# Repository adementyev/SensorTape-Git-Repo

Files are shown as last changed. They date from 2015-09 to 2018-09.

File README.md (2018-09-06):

# SensorTape Project 

## Introduction 
SensorTape is a sensor network in a form factor of a tape. It allows users to intuitively create large sensor networks. See mode details in the paper from [UIST](http://artem.dementyev.us/wp-content/uploads/2013/10/Sensor_tape_UIST_2015_rev9_FINAL.pdf) conference and a video 
This repository contains all the hardware and software design files to make SensorTape. 

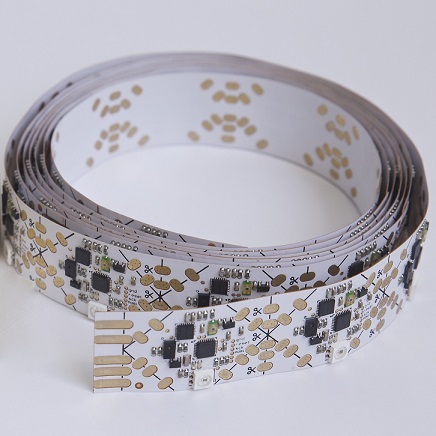
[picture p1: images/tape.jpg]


## Content
Master_hw/ - Hardware files for the master board in Altium format. Can be used to make the board

Slave_hw/ - Hardware files for the tape itself, refered here as the slave. This is the flexible circuit version of the tape 

Prog_adapter_hw/ -  Hardware files for the programming board, use it to program both the slave and the master. 

libraries/ - Collection of the Arduino libraries for the master and the slave. Those libraries are required 

Firmware/ - Firmware for both the master and the slave

SensorTape_Demo_V1/ - Processing sketch for a simple visualization demo. Demonstrates the basics of interfacing with a PC. 

## Getting Started
Connect the mini USB port on the master board to the computer. The master board has two usb ports and the micro USB port is only for 5V power. 
Connect the tape to the master using the FPC connector on the master. Make sure it secured. The tape has to be placed in the right orientation. There are 5 wires on the tape and the master, and they should match up. See the picture below. 

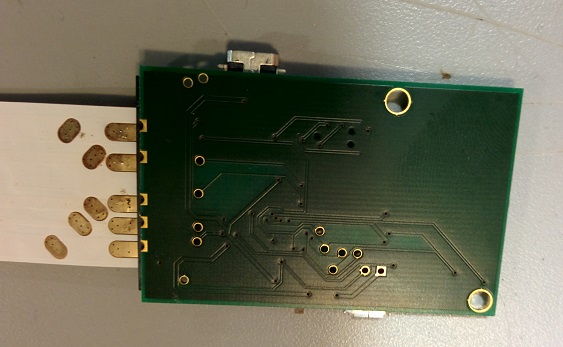
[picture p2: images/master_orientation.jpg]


Turn the switch on the master. The sensor nodes on the tape should light up. 
Once the initialization is done, the blue light will start blinking. 
The raw data can be seen on the serial terminal (at 115200 baud rate) 
The data visaulization can be done using the SensorTape_Demo_V1 software for Processing. In the code SensorTape_Demo_V1.pde. There is a line which defines number of nodes: 
int numberOfNodes = 16; 
This should be changed to the number you have, to make debugging easier. 
Also, if the number is incorrect, 3D visualizations will be messed up. 

The IMU sensors need some time to calibrate (about 30 seconds) after powering on. If they are moved during the time the orientation vectors will be messed up. 

## Firmware 
Add the arduino libraries from the libraries/ folder here to the worspace libraries folder. 
You will need the following libraries Adafruit_NeoPixel, I2C_dev, MPU6050, and VL6180X_I2C_Soft

you will need a programmer and an adapter board (Prog_adapter_hw/) to load the software. I used AVRISP mKII.
you will need to load the bootloader first into the boards. This will set the fuses and the clock frequency. Use the Arduino Micro (3.3V, 8 MHz) for the slaves and Arduino leonardo for the master. Set those before loading the bootloader

## PC software
I used Processing 3. You will need one external library (toxiclibs-complete-0020), it is in the libraries folder. 

## Slave
The slaves are basically the tape. The tape is made of strips with 6 slave nodes. You will need a flexible PCB factory to manufacture. The factories in china are innexpensive and have good quality. They can be found on alibaba.com. Also it is better to get it assembled profesionally, since hand assembly is difficult. I had a lot of problems with the packaging of proximity sensor melting in my reflow owen. 

The programming connector can be hard to attach on the first try, since it is just pressfitted. 

When starting the tape wait about a minute for the IMUs to calibrate, otherwise the orientaion data will drift

## Master
Master moves the data from the slaves to the PC. I am using an ATMega32u4 microcontroller, which works as a USB modem. 

## Known Issues
1. Proximity sometimes dont work if tape is restarted. I suspect that they don't have time to fully discharge. When turning the tape on and off or restarting, wait some time to turn it back on. 
2. The number of nodes is set pn the PC side in the current version. So the nodes dont need to be reset each time PC software is restarted. 

## Manufacturing and Design 
There are three parts needed for manufacturing: 
1) Manufacturing the flexible circuits 
2) Sourcing the parts 
3) Assembly (parts+flex circuit = done!)

We encourage manufacturing the SensorTape from the source files. There are numerous board houses that can do flexible electronics. The prices in the US are quite expensive (few thousand $$$), and the same boards can be made in China for a fraction of the price(few hundred $$$). On the other hand, it is easier to communicate with the US-based manufacturers. The Chinese board houses can be found and contacted directly on places such as Alibaba.com. 

The parts can be bought easily from US-based large electronics sellers such as Digikey.com. If you want the parts cheaper, go through Alibaba.com. It is more difficult, but can be cheaper especially for the ICs. 

The assembly should be done by a factory also, using professional equipment. Doing it by hand is possible, but requires a good reflow oven. The oven needs to have even temperature distribution, since proximity sensor packaging can easily melt. There are numerous assembly houses in the US, such as Advanced Circuits. They have reasonable prices (around a thousand). There are also assembly houses in China, that area cheaper, but once again are more difficult to contact.  

## Aknowledgements
MIT Media Lab, Nan-Wei Gong, Cindy Kao, Nan Zhao, Felix Heibeck, National Sceince Foundation. 
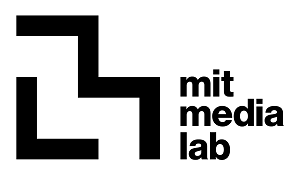
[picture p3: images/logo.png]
MediaLab Logo


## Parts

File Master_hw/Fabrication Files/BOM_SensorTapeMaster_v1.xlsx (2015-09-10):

Description | Quantity | Footprint | Comment | Manufacturer | Mfg Part # | Digikey Part # | Designator
Resistors
RES SMD 4.7K OHM 5% 1/10W 0603 | 2 | 0603 | Generic, can be subsituted with another manufacturer | Yageo | RC0603JR-074K7L | 311-4.7KGRCT-ND | R4,R5
RES SMD 1K OHM 5% 1/10W 0603 | 3 | 0603 | Generic, can be subsituted with another manufacturer | Yageo | RC0603JR-071KL | 311-1.0KGRCT-ND | R1,R3,R9
RES SMD 10K OHM 1% 1/10W 0603 | 2 | 0603 | Generic, can be subsituted with another manufacturer | Stackpole | RMCF0603FT10K0 | RMCF0603FT10K0CT-ND | R6,R12
RES SMD 22 OHM 5% 1/10W 0603 | 2 | 0603 | Generic, can be subsituted with another manufacturer | Yageo | RC0603JR-0722RL | 311-22GRCT-ND | R7,R8
RES ARRAY 330 OHM 4 RES 1206 | 1 | 1206 |  | Panasonic | EXB-38V331JV | Y9331CT-ND | R13
RES SMD 0.0OHM JUMPER 1/10W 0603 | 2 | 603 | Generic, can be subsituted with another manufacturer | Rohm | MCR03EZPJ000 | RHM0.0GCT-ND | R2,R10
Capacitors
CAP CER 0.1UF 16V 10% X7R 0603 | 4 | 0603 | Generic, can be subsituted with another manufacturer | Murata | GRM188R71C104KA01D | 490-1532-1-ND | C3, C4, C5, C8
CAP CER 10UF 6.3V 20% X5R 0603 | 3 | 0603 | Generic, can be subsituted with another manufacturer | Taiyo Yuden | JMK107ABJ106MAHT | 587-3383-1-ND | C1, C2, C9
CAP CER 1UF 10V 10% X7R 0603 | 1 | 0603 | Generic, can be subsituted with another manufacturer | Samsung | CL10B105KP8NNNC | 1276-1946-1-ND | C7
CAP CER 22PF 50V 5% C0G 0603 | 2 | 0603 | Generic, can be subsituted with another manufacturer | TDK | C1608C0G1H220J080AA | 445-1273-1-ND | C10,C11
LEDs
LED 468NM BLUE CLEAR 0603 SMD | 1 | 0603 |  | Lite-On Inc | LTST-C191TBKT | 160-1647-1-ND | L1
LED SUPER RED CLR THIN 0603 SMD | 2 | 0603 |  | Lite-On Inc | LTST-C191KRKT | 160-1447-1-ND | L2, L5
LED RED ORAN CLEAR THIN 0603 SMD | 1 | 0603 |  | Lite-On Inc | LTST-C191KFKT | 160-1445-1-ND | L3
LED WHITE 0603 SMD | 1 | 0603 |  | Lite-On Inc | LTW-C193TS5 | 160-1721-1-ND | L4
LED GREEN CLEAR THIN 0603 SMD | 1 | 0603 |  | Lite-On Inc | LTST-C191KGKT | 160-1446-1-ND | L6
LED RGB WS2812B 5050 W/DVR 10PK | 1 | 5050 |  | Adafruit | 1655 | 1528-1104-ND | L7
Resonators
Crystal 16.0000MHz 30ppm 18pF 60 Ohm | 1 | 4-SMD, No Lead (DFN, LCC) |  | CTS | 405C35D16M00000 | CTX820CT-ND | O2
ICs
IC MCU 8BIT 32KB FLASH 44QFN | 1 | 44-TQFP (10x10) |  | Atmel | ATMEGA32U4-AU | ATMEGA32U4-AU-ND | U5
IC LOAD SW CTRL 1CH SOT-25 | 1 | SOT-25 |  | Diodes inc | AP2280-1WG-7 | AP2280-1WGDICT-ND | U7
IC SWITCH HIGH SIDE SC70-6 | 1 | 6-TSSOP |  | Vishay | SIP32431DR3-T1GE3 | SIP32431DR3-T1GE3CT-ND | U4
MODULE BLUETOOTH V2.1+EDR | 1 | 35-SMD Module |  | Microchip | RN42-I/RM | 740-1038-ND | U1
IC REG LDO 3.3V 0.15A SOT23-5 | 1 | SOT-23-5 |  | Micrel | MIC5205-3.3YM5 TR | 576-1259-1-ND | U6
DNP | 1 | SOT-23-5 | DNP | Micrel | MIC5205-3.3YM5 TR | 576-1259-1-ND | U6
MAGNETOMETER XYZ DIGITAL 10DFN | 1 | 10-DFN (2x2) | Optional | Freescale | MAG3110FCR1 | MAG3110FCR1CT-ND | U3
Connectors
CONN FPC TOP 25POS 1.00MM | 1 |  |  | TE Connectivity | 2-84953-5 | A101410CT-ND | P6
Connector Receptacle USB - micro B | 1 |  |  | Hirose | ZX62-B-5PA(11) | H11634CT-ND | P3
Connector Receptacle USB - min | 1 |  |  | Hirose | UX60SC-MB-5ST(80) | H11671CT-ND | P4
TEST POINT PC MINI .040"D RED | 12 |  | DNP | Keystone electronics | 5000 | 36-5000-ND | TP1, TP2, TP3, TP4, TP5, TP6, TP7, TP8, TP9, TP10, TP11, TP12
Switches
SWITCH TACTILE SPST-NO 0.02A 15V | 1 |  |  | Panasonic | EVQ-Q2B02W | P12931SCT-ND | S1
SWITCH SLIDE SPDT 0.4VA 28V | 1 |  |  | NKK Switches | SS312SAH4-R | 360-2924-1-ND | S2

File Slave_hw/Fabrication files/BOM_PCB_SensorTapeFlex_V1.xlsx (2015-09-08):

Parts for one strip (6 identical circuits)
Description | Quantity | Footprint | Comment | Manufacturer | Mfg Part # | Digikey Part # | Designator
Capacitors
CAP CER 0.1UF 16V 10% X7R 0603 | 24 | 0603 | Generic, can be subsituted with another manufacturer | Murata | GRM188R71C104KA01D | 490-1532-1-ND | C1, C1_1, C1_1_1, C1_1_1_1, C1_1_1_2, C1_1_2, C2, C2_1, C2_1_1, C2_1_1_1, C2_1_1_2, C2_1_2, C5, C5_1, C5_1_1, C5_1_1_1, C5_1_1_2, C5_1_2, C6, C6_1, C6_1_1, C6_1_1_1, C6_1_1_2, C6_1_2
CAP CER 10000PF (10nF) 50V 10% X7R 0603 | 6 | 0603 | Generic, can be subsituted with another manufacturer | Murata | GRM188R71H103KA01D | 490-1512-1-ND | C3, C3_1, C3_1_1, C3_1_1_1, C3_1_1_2, C3_1_2
CAP CER 2200PF 50V 5% NP0 0603 | 6 | 0603 | Generic, can be subsituted with another manufacturer | Murata | GRM1885C1H222JA01D | 490-1459-1-ND | C4, C4_1, C4_1_1, C4_1_1_1, C4_1_1_2, C4_1_2
CAP CER 10UF 6.3V 20% X5R 0603 | 18 | 0603 | Generic, can be subsituted with another manufacturer | Taiyo Yuden | JMK107ABJ106MAHT | 587-3383-1-ND | C7, C7_1, C7_1_1, C7_1_1_1, C7_1_1_2, C7_1_2, C8, C8_1, C8_1_1, C8_1_1_1, C8_1_1_2, C8_1_2, C9, C9_1, C9_1_1, C9_1_1_1, C9_1_1_2, C9_1_2
Resistors
RES SMD 4.7K OHM 5% 1/10W 0603 | 6 | 0603 | Generic, can be subsituted with another manufacturer | Yageo | RC0603JR-074K7L | 311-4.7KGRCT-ND | R3, R3_1, R3_1_1, R3_1_1_1, R3_1_1_2, R3_1_2
RES SMD 1K OHM 1% 1/10W 0603 | 6 | 0603 | Generic, can be subsituted with another manufacturer | Yageo | RC0603FR-071KL | 311-1.00KHRCT-ND | R7, R7_1, R7_1_1, R7_1_1_1, R7_1_1_2, R7_1_2
RES SMD 47K OHM 1% 1/10W 0603 | 12 | 0603 | Generic, can be subsituted with another manufacturer | Yageo | RC0603FR-0747KL | 311-47.0KHRCT-ND | R8, R8_1, R8_1_1, R8_1_1_1, R8_1_1_2, R8_1_2, R9, R9_1, R9_1_1, R9_1_1_1, R9_1_1_2, R9_1_2
RES SMD 330 OHM 1% 1/10W 0603 | 12 | 0603 | Generic, can be subsituted with another manufacturer | Yageo | RC0603FR-07330RL | 311-330HRCT-ND | R10, R10_1, R10_1_1, R10_1_1_1, R10_1_1_2, R10_1_2, R11, R11_1, R11_1_1, R11_1_1_1, R11_1_1_2, R11_1_2
RES SMD 10K OHM 1% 1/10W 0603 | 24 | 0603 | Generic, can be subsituted with another manufacturer | Stackpole Electronics | RMCF0603FT10K0 | RMCF0603FT10K0CT-ND | R1, R1_1, R1_1_1, R1_1_1_1, R1_1_1_2, R1_1_2, R2, R2_1, R2_1_1, R2_1_1_1, R2_1_1_2, R2_1_2, R4, R4_1, R4_1_1, R4_1_1_1, R4_1_1_2, R4_1_2, R6, R6_1, R6_1_1, R6_1_1_1, R6_1_1_2, R6_1_2
Resonators
CER RESONATOR 8.00MHZ SMD | 6 | 3-SMD, Non-Standard |  | Murata | CSTCE8M00G55-R0 | 490-1195-1-ND | O1, O1_1, O1_1_1, O1_1_1_1, O1_1_1_2, O1_1_2
LEDs
WS2812S 6 pin RGB LED | 6 | 5050 | Has to be the 6 pin version (S version) | Worldsemi | WS2812S |  | L1, L1_1, L1_1_1, L1_1_1_1, L1_1_1_2, L1_1_2
LED 468NM BLUE CLEAR 0603 SMD | 6 | 0603 | Generic, can be subsituted with another manufacturer | Lite-On Inc | LTST-C191TBKT | 160-1647-1-ND | L2, L2_1, L2_1_1, L2_1_1_1, L2_1_1_2, L2_1_2
LED SUPER RED CLR THIN 0603 SMD | 6 | 603 | Generic, can be subsituted with another manufacturer | Lite-On Inc | LTST-C191KRKT | 160-1447-1-ND | L3, L3_1, L3_1_1, L3_1_1_1, L3_1_1_2, L3_1_2
ICs
AMBIENT LIGHT SENSOR 1206 SMD | 6 | 1206 |  | Vishay | TEMT6000X01 |  | T1, T1_1, T1_1_1, T1_1_1_1, T1_1_1_2, T1_1_2
GYRO/ACCELEROMETER 6AXIS 24QFN | 6 | QFN24 |  | Invensense | MPU-6050 |  | U1, U1_1, U1_1_1, U1_1_1_1, U1_1_1_2, U1_1_2
ATmega328P-MUR | 6 | 32-VFQFN Exposed Pad |  | Atmel | ATMEGA328P-MU |  | U2, U2_1, U2_1_1, U2_1_1_1, U2_1_1_2, U2_1_2
MOD TIME-OF-FLIGHT 3IN1 12LGA | 6 | 12LGA |  | STMicroelectronics | VL6180XV0NR/1 |  | U3, U3_1, U3_1_1, U3_1_1_1, U3_1_1_2, U3_1_2
IC REG LDO 2.8V 0.15A SOT23-5 | 6 | SOT-23-5 |  | Micrel | MIC5205-2.8YM5 TR |  | U4, U4_1, U4_1_1, U4_1_1_1, U4_1_1_2, U4_1_2,
IC REG LDO 3.3V 0.15A SOT23-5 | 6 | SOT-23-5 |  | Micrel | MIC5205-3.3YM5 TR |  | U5, U5_1, U5_1_1, U5_1_1_1, U5_1_1_2, U5_1_2

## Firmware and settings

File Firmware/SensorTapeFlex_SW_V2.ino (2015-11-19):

//This is for tape flexible pcb version of the tape (SensorTapeFlex_V1)
//Use Arduino Micro (8MHz, 3.3V)
//Author: Artem Dementyev
//Modified on Septeber 9,2015

//I2C pins are switched from the Rigid PCB Version: 
//CHANGE the I2Cdev.h  SDA_PIN and SCL_PIN 

 
#include "I2Cdev.h"
#include "MPU6050_6Axis_MotionApps20.h"
#include <SPI.h>
#include <Wire.h>
#include <SoftwareSerial.h>
#include <Adafruit_NeoPixel.h>
#include "VL6180X_I2C_Soft.h"

MPU6050 mpu;
SoftwareSerial p2pSerial(9,10); //RX, TX

#define PIN_RGB_LED    7
#define LED_BLUE       6
#define LED_RED        5
#define ADC_LIGHT_PIN  A2
//#define CUT_1     A1      
//#define CUT_2     8
#define NUMPIXELS      1  
#define VL6180X_ADDRESS 0x29


bool blinkState = false;

// MPU control/status vars
bool dmpReady = false;  // set true if DMP init was successful
uint8_t mpuIntStatus;   // holds actual interrupt status byte from MPU
uint8_t devStatus;      // return status after each device operation (0 = success, !0 = error)
uint16_t packetSize;    // expected DMP packet size (default is 42 bytes)
uint16_t fifoCount;     // count of all bytes currently in FIFO
uint8_t fifoBuffer[64]; // FIFO storage buffer

// orientation/motion vars
Quaternion q;           // [w, x, y, z]         quaternion container
VectorInt16 aa;         // [x, y, z]            accel sensor measurements
VectorInt16 aaReal;     // [x, y, z]            gravity-free accel sensor measurements
VectorInt16 aaWorld;    // [x, y, z]            world-frame accel sensor measurements
VectorFloat gravity;    // [x, y, z]            gravity vector

// packet structure for InvenSense teapot demo
uint8_t teapotPacket[14] = { '$', 0x02, 0,0, 0,0, 0,0, 0,0, 0x00, 0x00, '\r', '\n' };
//global variables
int numberOfSensors = 3;
int deviceType = 1;
int deviceID = 0; 
int cut1pin = A1; 
int cut2pin = 8; 
boolean startUp = true; 
int incomingByte = 0;
byte val1; 
byte val2;  
int lightAnalogRead = 2000; 
int thermistorAnalogRead = 3000; 
int positionAnalogRead = 4000;
String valueString = "a"; 
byte valAll[1]; 
uint8_t distanceReading =0x10; 
uint8_t masterReceive[3] = {0x00,0x00,0x00} ;

Adafruit_NeoPixel pixels = Adafruit_NeoPixel(NUMPIXELS, PIN_RGB_LED, NEO_GRB + NEO_KHZ800);
VL6180x distanceSensor(VL6180X_ADDRESS);

// ================================================================
// ===               INTERRUPT DETECTION ROUTINE FOR IMU        ===
// ================================================================

volatile bool mpuInterrupt = false;     // indicates whether MPU interrupt pin has gone high
void dmpDataReady() {
    mpuInterrupt = true;
}

// ================================================================
// ===                      INITIAL SETUP                       ===
// ================================================================

void setup() {
    //set pins  
    pinMode(LED_BLUE, OUTPUT);   
    pinMode(LED_RED, OUTPUT); 
    digitalWrite(LED_BLUE, HIGH); 
  
    SPI.begin();
    p2pSerial.begin(9600);
    delay(50); 
  
    //Wait until data from peer to peer network
    while(true){ 
      if(p2pSerial.available()>1) { 
        if(p2pSerial.read()==200) { 
          incomingByte = p2pSerial.read();
          //assign address from incoming data  
          deviceID=incomingByte; 
  
          //send data to the next device
          p2pSerial.write(200);
          p2pSerial.write(incomingByte+1);
          digitalWrite(LED_BLUE, LOW);  
          break; 
        }
      }
    }//end while
    p2pSerial.end(); 
  
    I2Cdev::i2c_init();

    //Start imu and proximity initialization
    mpu.initialize();
    distanceSensor.VL6180xInit();
  
    devStatus = mpu.dmpInitialize();
    distanceSensor.VL6180xDefautSettings();
    distanceSensor.VL6180x_setRegister(VL6180X_SYSTEM_FRESH_OUT_OF_RESET  , 0x00); 
    distanceSensor.VL6180x_setRegister(VL6180X_SYSRANGE_START, 0x01); //Start the 100ms continous operation.
   
    // supply your own gyro offsets here, scaled for min sensitivity
    mpu.setXGyroOffset(220);
    mpu.setYGyroOffset(76);
    mpu.setZGyroOffset(-85);
    mpu.setZAccelOffset(1788); // 1688 factory default for my test chip
    
    
    mpu.setDMPEnabled(true);
    // enable Arduino interrupt detection
    mpuIntStatus = mpu.getIntStatus();
    dmpReady = true;
    packetSize = mpu.dmpGetFIFOPacketSize(); 
    
    Wire.begin(deviceID); // Start I2C Bus as a Slave (Device Number 2)
    Wire.onRequest(requestEvent); // register event to send data to master (respond to requests)
    Wire.onReceive(receiveEvent); //register even to receice data from master
    attachInterrupt(0, dmpDataReady, RISING);
     
    pixels.begin(); // This initializes the NeoPixel library.
    pixels.setPixelColor(0, pixels.Color(0,10,0)); // Moderately bright green color.
    pixels.show(); // This sends the updated pixel color to the hardware.    
}//end setup

// ================================================================
// ===                    MAIN PROGRAM LOOP                     ===
// ================================================================

void loop() {
      //This is the MAIN LOOP
     while (!mpuInterrupt && fifoCount < packetSize) {
            //DO nothing, wait for interrupts 
      }//end while
    
    //STEPPING OUT OF THE LOOP FOR INTERRUPT  
    // reset interrupt flag and get INT_STATUS byte
    mpuInterrupt = false;
    mpuIntStatus = mpu.getIntStatus();
    
    // get current FIFO count
    fifoCount = mpu.getFIFOCount();
    
    if ((mpuIntStatus & 0x10) || fifoCount == 1024) {
        // reset so we can continue cleanly
        mpu.resetFIFO();
    //    Serial.println(F("FIFO overflow!"));

    // otherwise, check for DMP data ready interrupt (this should happen frequently)
    } else if (mpuIntStatus & 0x02) {
        // wait for correct available data length, should be a VERY short wait
        while (fifoCount < packetSize) fifoCount = mpu.getFIFOCount();

        // read a packet from FIFO
        mpu.getFIFOBytes(fifoBuffer, packetSize);
        
        // track FIFO count here in case there is > 1 packet available
        // (this lets us immediately read more without waiting for an interrupt)
        fifoCount -= packetSize;

       
        // display quaternion values in InvenSense Teapot demo format:
        teapotPacket[2] = fifoBuffer[0];
        teapotPacket[3] = fifoBuffer[1];
        teapotPacket[4] = fifoBuffer[4];
        teapotPacket[5] = fifoBuffer[5];
        teapotPacket[6] = fifoBuffer[8];
        teapotPacket[7] = fifoBuffer[9];
        teapotPacket[8] = fifoBuffer[12];
        teapotPacket[9] = fifoBuffer[13];
        teapotPacket[11]++; // packetCount, loops at 0xFF on purpose

       //get data from priximity sensor 
       if(!startUp) {  
         noInterrupts();
         char range_status = distanceSensor.VL6180x_getRegister(VL6180X_RESULT_INTERRUPT_STATUS_GPIO) & 0x07;
         // wait for new measurement ready status
         if (range_status == 0x04) {
             distanceReading = distanceSensor.VL6180x_getRegister(VL6180X_RESULT_RANGE_VAL); 
             distanceSensor.VL6180x_setRegister(VL6180X_SYSTEM_INTERRUPT_CLEAR, 0x07);
             distanceSensor.VL6180x_setRegister(VL6180X_SYSRANGE_START, 0x01); //Start Single shot mode
             digitalWrite(LED_BLUE, !digitalRead(LED_BLUE));
         }//end if
         interrupts();
       }
    }//end else if 
}//end loop

//This function assembles a reply to a master's request
void requestEvent()
{
    //The communication sends the number of sensors and type of device. 
    if (startUp) { 
        byte a = deviceID & 0xFF; //Use this format to send 16bit integer to java. 
        byte b = (deviceID >>8 ) & 0xFF;
        
        byte c = numberOfSensors & 0xFF; ; 
        byte d = (numberOfSensors >>8 ) & 0xFF;
        
        byte e = deviceType & 0xFF; ; 
        byte f = (deviceType >>8 ) & 0xFF;
        
        int tempread = digitalRead(cut1pin); 
        byte g = tempread & 0xFF; ; 
        byte h = (tempread >>8 ) & 0xFF;     
        
        tempread = digitalRead(cut2pin); 
        byte i = tempread & 0xFF; ; 
        byte j = (tempread >>8 ) & 0xFF;   
        
        tempread = digitalRead(cut2pin); 
        byte k = tempread & 0xFF; ; 
        byte l = (tempread >>8 ) & 0xFF; 
        
        tempread = digitalRead(cut2pin); 
        byte m = tempread & 0xFF; ; 
        byte n = (tempread >>8 ) & 0xFF; 
        
        byte All [] = {a,b,c,d,e,f,g,h,i,j,k,l,m,n};  
           
        Wire.write(All, 14); // respond with message 
        startUp = false;
    } 

    //Otterwise, send data from the on-board sensors. 
    else { 
        digitalWrite(LED_RED, HIGH);
        lightAnalogRead = analogRead(ADC_LIGHT_PIN); // Read light value 
        thermistorAnalogRead = lightAnalogRead; //Read thermistor valie
        //positionAnalogRead = analogRead(A1); //Read position
        
        byte a = deviceID & 0xFF;
        byte b = (deviceID >>8 ) & 0xFF;
        
        byte c = lightAnalogRead & 0xFF; ; 
        byte d = (lightAnalogRead >>8 ) & 0xFF;
     
        byte e = thermistorAnalogRead & 0xFF; ; 
        byte f = (thermistorAnalogRead >>8 ) & 0xFF;
        
        byte g = distanceReading & 0xFF;
        byte h = (0x00 >>8 ) & 0xFF;
       
        byte All [] = {a,b,c,d,e,f,g,h, 
                      fifoBuffer[1], fifoBuffer[0], 
                      fifoBuffer[5], fifoBuffer[4], 
                      fifoBuffer[9], fifoBuffer[8],
                      fifoBuffer[13], fifoBuffer[12]};     
        
        byte *mypointer; 
        mypointer = All;
        byte crc8 = CRC8(mypointer, 16);
        
        byte data [] = {a,b,c,d,e,f,g,h, 
              fifoBuffer[1], fifoBuffer[0], 
              fifoBuffer[5], fifoBuffer[4], 
              fifoBuffer[9], fifoBuffer[8],
              fifoBuffer[13], fifoBuffer[12],
              crc8, 0x00}; 
                        
        Wire.write(data, 18); 
        digitalWrite(LED_RED, LOW);    
    }//end else        
}//end requestEvent

//This function sets led color based on master command
void receiveEvent(int howMany)
{
  if (Wire.available()) {    
      masterReceive[0] = Wire.read(); 
      masterReceive[1] = Wire.read(); 
      masterReceive[2] = Wire.read(); 
  }
     pixels.setPixelColor(0, pixels.Color(masterReceive[0],masterReceive[1],masterReceive[2])); 
     pixels.show();
}

int readInternalTemperature() {
    int result;
    // Read temperature sensor against 1.1V reference
    ADMUX = _BV(REFS1) | _BV(REFS0) | _BV(MUX3);
    delay(2); // Wait for Vref to settle
    ADCSRA |= _BV(ADSC); // Convert
    while (bit_is_set(ADCSRA,ADSC));
    result = ADCL;
    result |= ADCH<<8;
    //result = (result - 125) * 1075;
    return result;
}

//CRC-8 - based on the CRC8 formulas by Dallas/Maxim
//From here: 
///http://www.leonardomiliani.com/en/2013/un-semplice-crc8-per-arduino/
byte CRC8(const byte *data, byte len) {
  byte crc = 0x00;
  while (len--) {
    byte extract = *data++;
    for (byte tempI = 8; tempI; tempI--) {
      byte sum = (crc ^ extract) & 0x01;
      crc >>= 1;
      if (sum) {
        crc ^= 0x8C;
      }
      extract >>= 1;
    }
  }
  return crc;
}

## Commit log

2015-09-08 Added Altium Files
    design files
    [PCB_SensorTapeFlex_v1.PcbDoc, Project_SensorTapeFlex_v1.PrjPcb, Schematic_SensorTapeFlex_v1.SchDoc]
2015-09-08 changed directories
    dir
    [PCB_SensorTapeFlex_v1.PcbDoc, Project_SensorTapeFlex_v1.PrjPcb, Schematic_SensorTapeFlex_v1.SchDoc]
2015-09-08 changed dirrs
    [PCB_SensorTapeFlex_v1.PcbDoc, Project_SensorTapeFlex_v1.PrjPcb, Schematic_SensorTapeFlex_v1.SchDoc]
2015-09-08 added fabrication files
    fab
    [PCB_SensorTapeFlex_v1.GBL, PCB_SensorTapeFlex_v1.GBP, PCB_SensorTapeFlex_v1.GBS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]
2015-09-08 added BOM
    BOM
    [BOM_PCB_SensorTapeFlex_V1.xlsx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]
2015-09-09 added master HW files
    [PCB_SensorTapeMaster_v1.GBL, PCB_SensorTapeMaster_v1.GBP, PCB_SensorTapeMaster_v1.GBS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]
2015-09-10 prog adapter
    [PCB_ProgAdapter_v1.PcbDoc, Project_ProgAdapter_v1.PrjPCB, Schematic.ProgAdapter_v1.SchDoc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]
2015-09-10 modified master hw
    [PCB_SensorTapeMaster_v1.GBL, PCB_SensorTapeMaster_v1.GBP, PCB_SensorTapeMaster_v1.GBS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]
2015-09-10 master HW small changes
    [PCB_SensorTapeMaster_v1.PcbDoc]
2015-09-10 top overlay change
    [PCB_SensorTapeMaster_v1.GTO]
2015-09-10 schematic master change
    [BOM_SensorTapeMaster_v1.xlsx, Schematic_SensorTapeMaster_v1.SchDoc]
2015-09-15 change PC software
    added 3D orientation and sensors together
2015-11-19 version 2 of tape node firmware
    Added CRC check and removed temperature sensing to make it faster
    [PCB_SensorTapeMaster_v1.PcbDoc]
